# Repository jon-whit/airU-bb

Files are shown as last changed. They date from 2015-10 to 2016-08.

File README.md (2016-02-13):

airU
airU-bb
=====
The airU project is an interdisciplinary project by University of Utah Computer Science, Chemical Engineering, and Computer Engineering students who have designed a low cost air-quality sensor platform that is suited to improving our understanding of the Wasatch Front’s air quality challenges.  The project hopes to provide:

- A broad collection of air quality data, with tools that enable individuals to visualize, interpret, and download real-time data interactively.
- Low cost air quality stations that can communicate wireless with centralized databases (be it government or commercial)
- Innovative transportation routes based on air quality index rating (long term)

Contribute
----------
Please see the contribution guidelines in [CONTRIBUTING.md](./CONTRIBUTING.md).

- Issue Tracker: https://github.com/jon-whit/airU-bb/issues
- Source Code: https://github.com/jon-whit/airU-bb

Support
-------
If you are having issues, please feel free to email us.

We have a mailing list located at: airu-help@utah.edu

License
-------
See [LICENSE.md](./LICENSE.md)

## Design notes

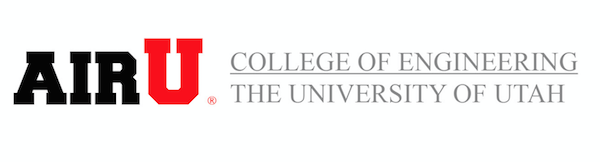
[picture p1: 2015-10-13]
airU.png

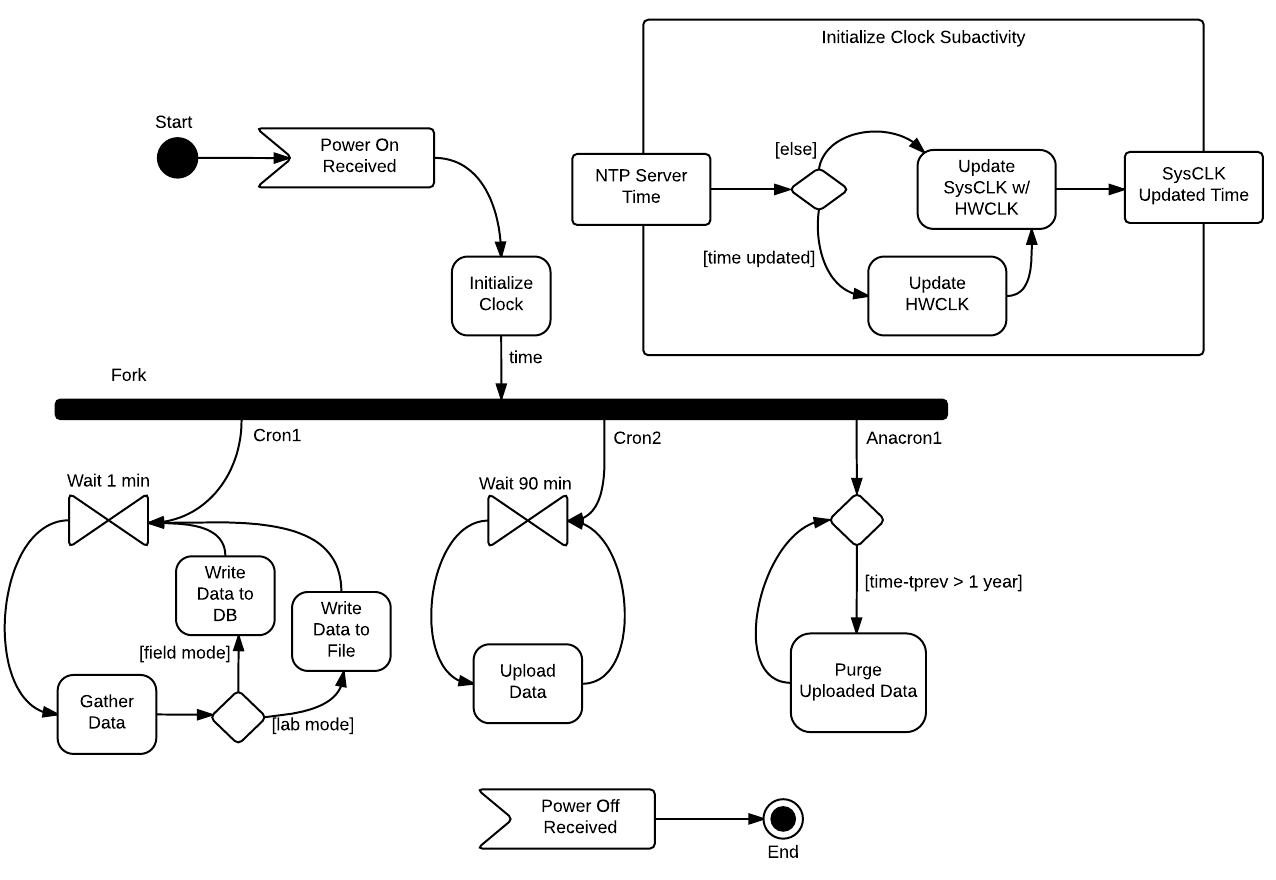
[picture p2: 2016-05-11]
Documents/Toolchain Activity Diagram.png

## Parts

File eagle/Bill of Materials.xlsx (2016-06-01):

Description | Quantity | Manufac. Part # | Mouser Part # | DigiKey Part # | MouseReel Available | DigiKeyReel Available | Unit Cost | Total Cost
Pressure Sensor & Digital Barometer | 1 | BMP180 | 262-BMP180 (http://www.mouser.com/ProductDetail/Bosch-Sensortec/BMP180/?qs=d72FGnIDsgTlLIC5YM2WKA%3D%3D) | N/A | Yes | N/A | $3.70 | $3.70
DHT22 Temp/Humidity Sensor | 1 | 385 (https://www.adafruit.com/products/385) | 485-385 (http://www.mouser.com/ProductDetail/Adafruit/385/) | N/A | Yes | N/A | $9.95 | $9.95
MICS 4514 (CO/NO2) Sensor | 1 | MICS-4514 (http://www.cdiweb.com/ProductDetail/MICS4514-SGX-Sensortech-Limited-formerly-e2v/333417/) | N/A | N/A | N/A | N/A | $9.72 | $9.72
MTK3339 GPS Chipset | 1 | Ultimate GPS Module (https://www.adafruit.com/products/790) |  |  |  |  | $29.95 | $29.95
DS1307 (Real Time Clock) | 1 | DS1307+ (http://www.mouser.com/ds/2/256/DS1307-99500.pdf) | 700-DS1307 (http://www.mouser.com/ProductDetail/Maxim-Integrated/DS1307+/?qs=sGAEpiMZZMsWkX3fPoxIPao0OKuDwxf4) | N/A | No | N/A | $3.32 | $3.32
U.FL RECEPTACLE SMT | 1 | 798-U.FL-R-SMT-110 (http://www.mouser.com/ProductDetail/Hirose-Connector/UFL-R-SMT-110/) | U.FL-R-SMT-1(10) (http://www.mouser.com/ProductDetail/Hirose-Connector/UFL-R-SMT-110/) | N/A | Yes | N/A | $1.29 | $1.29
SMD Green LED 571nm | 1 | 59-LTST-C230KGKT (http://www.mouser.com/ProductDetail/Lite-On/LTST-C230KGKT/?qs=sGAEpiMZZMseGfSY3csMkdPLvDBdRu8edtj8jOiqvGY%3d) | LTST-C230KGKT (http://www.mouser.com/ProductDetail/Lite-On/LTST-C230KGKT/?qs=sGAEpiMZZMseGfSY3csMkdPLvDBdRu8edtj8jOiqvGY%3d) | 160-1456-6-ND (http://www.digikey.com/product-detail/en/LTST-C230KGKT/160-1456-6-ND/1888661) | Yes | Yes | $0.64 | $0.64
PMS3003 Wire Housing | 1 | 53261-0871 (http://www.mouser.com/ds/2/276/0532610871_PCB_HEADERS-171054.pdf) | 538-53261-0871 (http://www.mouser.com/ProductDetail/Molex/53261-0871/?qs=%2b72YyncTwW%2bggfdCJ7Netw%3D%3D) | WM7626DKR-ND (http://www.digikey.com/product-detail/en/0532610871/WM7626DKR-ND/1846794) | Yes | Yes | $1.82 | $1.82
Ferrite Bead | 1 | MMZ2012R102A (http://www.mouser.com/ds/2/400/e9412_mmz-24297.pdf) | 810-MMZ2012R102A (http://www.mouser.com/ProductDetail/TDK/MMZ2012R102A/) | 445-1555-1-ND (http://www.digikey.com/product-detail/en/MMZ2012R102AT000/445-1555-1-ND/571885) | Yes | Yes | $0.11 | $0.11
SPDT Switch (SMT) | 1 | PCM12SMTR (http://www.mouser.com/ds/2/60/PCM_7jan16-24112.pdf) | 611-PCM12SMTR (http://www.mouser.com/ProductDetail/CK-Components/PCM12SMTR/?qs=sGAEpiMZZMtHXLepoqNyVcCjmOJVOBZeAfXRWWbW3TQ%3d) |  |  |  | $0.77 | $0.77
32.768kHz oscillator | 1 | FX122-327 (http://www.foxonline.com/pdfs/FX122.pdf) | N/A | 631-1261-1-ND (http://www.digikey.com/product-search/en?keywords=631-1261-1-ND) | N/A | Yes | $1.02 | $1.02
20mm Coin Cell Battery Holder | 1 | 12BH002-GR (http://www.mouser.com/ds/2/209/epd_10012015_12BH002-GR-770925.pdf) | 12BH002-GR (http://www.mouser.com/ProductDetail/Eagle-Plastic-Devices/12BH002-GR/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) |  |  |  | $0.46 | $0.46
SMD 1206 1/4watt 10Kohms 1% by Vishay | 5 | CRCW120610K0FKEA (http://www.mouser.com/ProductDetail/Vishay-Dale/CRCW120610K0FKEA/) | 71-CRCW1206-10K-E3 (http://www.mouser.com/ProductDetail/Vishay-Dale/CRCW120610K0FKEA/) | 541-10.0KFDKR-ND (http://www.digikey.com/product-detail/en/CRCW120610K0FKEA/541-10.0KFDKR-ND/1183732) | Yes | Yes | $0.37 | $1.86
SMD 1206 1/4watt 1Kohms 1% | 1 | RK73H2BTTD1001F (http://www.mouser.com/ProductDetail/KOA-Speer/RK73H2BTTD1001F/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) | 660-RK73H2BTTD1001F (http://www.mouser.com/ProductDetail/KOA-Speer/RK73H2BTTD1001F/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) |  |  |  | $0.10 | $0.10
SMD 1206 1/4watt 82ohms 1% by Vishay | 2 | CRCW120682R0FKEA (http://www.mouser.com/ds/2/427/dcrcwe3-109170.pdf) | 71-CRCW1206-82-E3 (http://www.mouser.com/ProductDetail/Vishay-Dale/CRCW120682R0FKEA/) | 541-82.0FCT-ND (http://www.digikey.com/product-detail/en/CRCW120682R0FKEA/541-82.0FCT-ND/1181636) | Yes | Yes | $0.10 | $0.20
SMD 1206 1/4watt 51ohms 1% by Vishay | 1 | CRCW120651R0FKEA (http://www.mouser.com/ds/2/427/dcrcwe3-109170.pdf) | 71-CRCW1206-51-E3 (http://www.mouser.com/ProductDetail/Vishay-Dale/CRCW120651R0FKEA/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) | 541-51.0UCT-ND (http://www.digikey.com/product-detail/en/CRCW120651R0FKEAHP/541-51.0UCT-ND/2826136) | Yes | Yes | $0.10 | $0.10
SMD 1206 1/4watt 620ohms 1% by Vishay | 1 | CRCW1206620RFKEA (http://www.mouser.com/ds/2/427/dcrcwe3-109170.pdf) | 71-CRCW1206-620-E3 (http://www.mouser.com/ProductDetail/Vishay-Dale/CRCW1206620RFKEA/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) | 541-620FTR-ND (http://www.digikey.com/product-detail/en/CRCW1206620RFKEA/541-620FTR-ND/1176621) | Yes | Yes | $0.10 | $0.10
SMD 1206 1/4watt 453ohms 1% by Vishay | 1 | CRCW1206453RFKEA (http://www.mouser.com/ds/2/427/dcrcwe3-109170.pdf) | 71-CRCW1206-453-E3 (http://www.mouser.com/ProductDetail/Vishay-Dale/CRCW1206453RFKEA/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) | N/A | Yes | N/A | $0.10 | $0.10
SMD 1206 1/4watt 62kohms 1% by Vishay | 1 | CRCW120662K0FKEA (http://www.mouser.com/ds/2/427/dcrcwe3-109170.pdf) | 71-CRCW1206-62K-E3 (http://www.mouser.com/ProductDetail/Vishay-Dale/CRCW120662K0FKEA/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) | 541-62.0KFCT-ND (http://www.digikey.com/product-detail/en/CRCW120662K0FKEA/541-62.0KFCT-ND/1181965) | Yes | Yes | $0.10 | $0.10
SMD 1206 1/4watt 33k0hms 1% by Vishay | 1 | CRCW120633K0FKEA (http://www.mouser.com/ds/2/427/dcrcwe3-109170.pdf) | 71-CRCW1206-33K-E3 (http://www.mouser.com/ProductDetail/Vishay-Dale/CRCW120633K0FKEA/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) | 541-33.0KFCT-ND (http://www.digikey.com/product-detail/en/CRCW120633K0FKEA/541-33.0KFCT-ND/1181931) | Yes | Yes | $0.10 | $0.10
SMD/SMT 1206 16volts 0.1uF X7R 10% | 4 | C1206C104K4RACTU (http://www.digikey.com/product-detail/en/C1206C104K4RACTU/399-9305-6-ND/3523376) | 80-C1206C104K4R (http://www.mouser.com/Search/ProductDetail.aspx) | 399-9305-6-ND (http://www.digikey.com/product-detail/en/C1206C104K4RACTU/399-9305-6-ND/3523376) | Yes | Yes | $0.36 | $1.43
SMD/SMT 1206 10uF 10volts X5R 10% | 2 | GRM31CR61A106KA01L (http://www.mouser.com/ProductDetail/Murata-Electronics/GRM31CR61A106KA01L/) | 81-GRM426R106K10L (http://www.mouser.com/ProductDetail/Murata-Electronics/GRM31CR61A106KA01L/) | GRM31CR61A106KA01L (http://www.digikey.com/product-detail/en/GRM31CR61A106KA01L/490-1820-6-ND/1825987) | Yes | Yes | $0.55 | $1.11
N-Channel MOSFET | 1 | BSS138LT1G (http://www.mouser.com/ds/2/308/BSS138LT1-D-104046.pdf) | 863-BSS138LT1G (http://www.mouser.com/ProductDetail/ON-Semiconductor/BSS138LT1G/) | BSS138LT1GOSCT-ND (http://www.digikey.com/product-detail/en/BSS138LT1G/BSS138LT1GOSCT-ND/917858) | Yes | Yes | $0.24 | $0.24
OSH Park PCBs | 3 | $38 | $13 per board
Total Estimated Cost per Board | $81.19

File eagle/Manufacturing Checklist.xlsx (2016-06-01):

 | Quantity | Value/Description | Unit | Additional | Key
Passives (No Orientation) | Resistors
 | 5 | 10k | Ohm |  | Oven Soldered
 | 1 | 1 | Ohm |  | Hand Soldered
 | 1 | 51 | Ohm
 | 2 | 82 | Ohm
 | 1 | 33k | Ohm
 | 1 | 453 | Ohm
 | 1 | 62 | Ohm
 | 1 | 620 | Ohm
 | Capacitors
 | 4 | 0.1u | Farad
 | 2 | 10u | Farad
 | 1 | LED | N/A
 | 1 | Ferrite Bead | N/A
 | 1 | 32.768k Oscillator | Hz
 | Sensors
 | 1 | BMP180 | Pressure, Temp, Alt
 | 1 | MTK3339 (GPS) | N/A | Large and square
 | 1 | MICS4514 | CO & NO2
 | 1 | DHT22 | Temp, Humidity
 | Special
 | 1 | N-channel MOSFET | N/A | 3-peg chip
 | 1 | Slide Switch | N/A
 | 1 | U.FL Receptical | N/A | Beneath GPS chip
 | 1 | Coin Cell Battery Clip | N/A | Back side of board
 | 1 | Wire Housing for PMS3003 | N/A | Back side of board
 | 1 | DS1307 (RTC) | N/A | Top side through-hole

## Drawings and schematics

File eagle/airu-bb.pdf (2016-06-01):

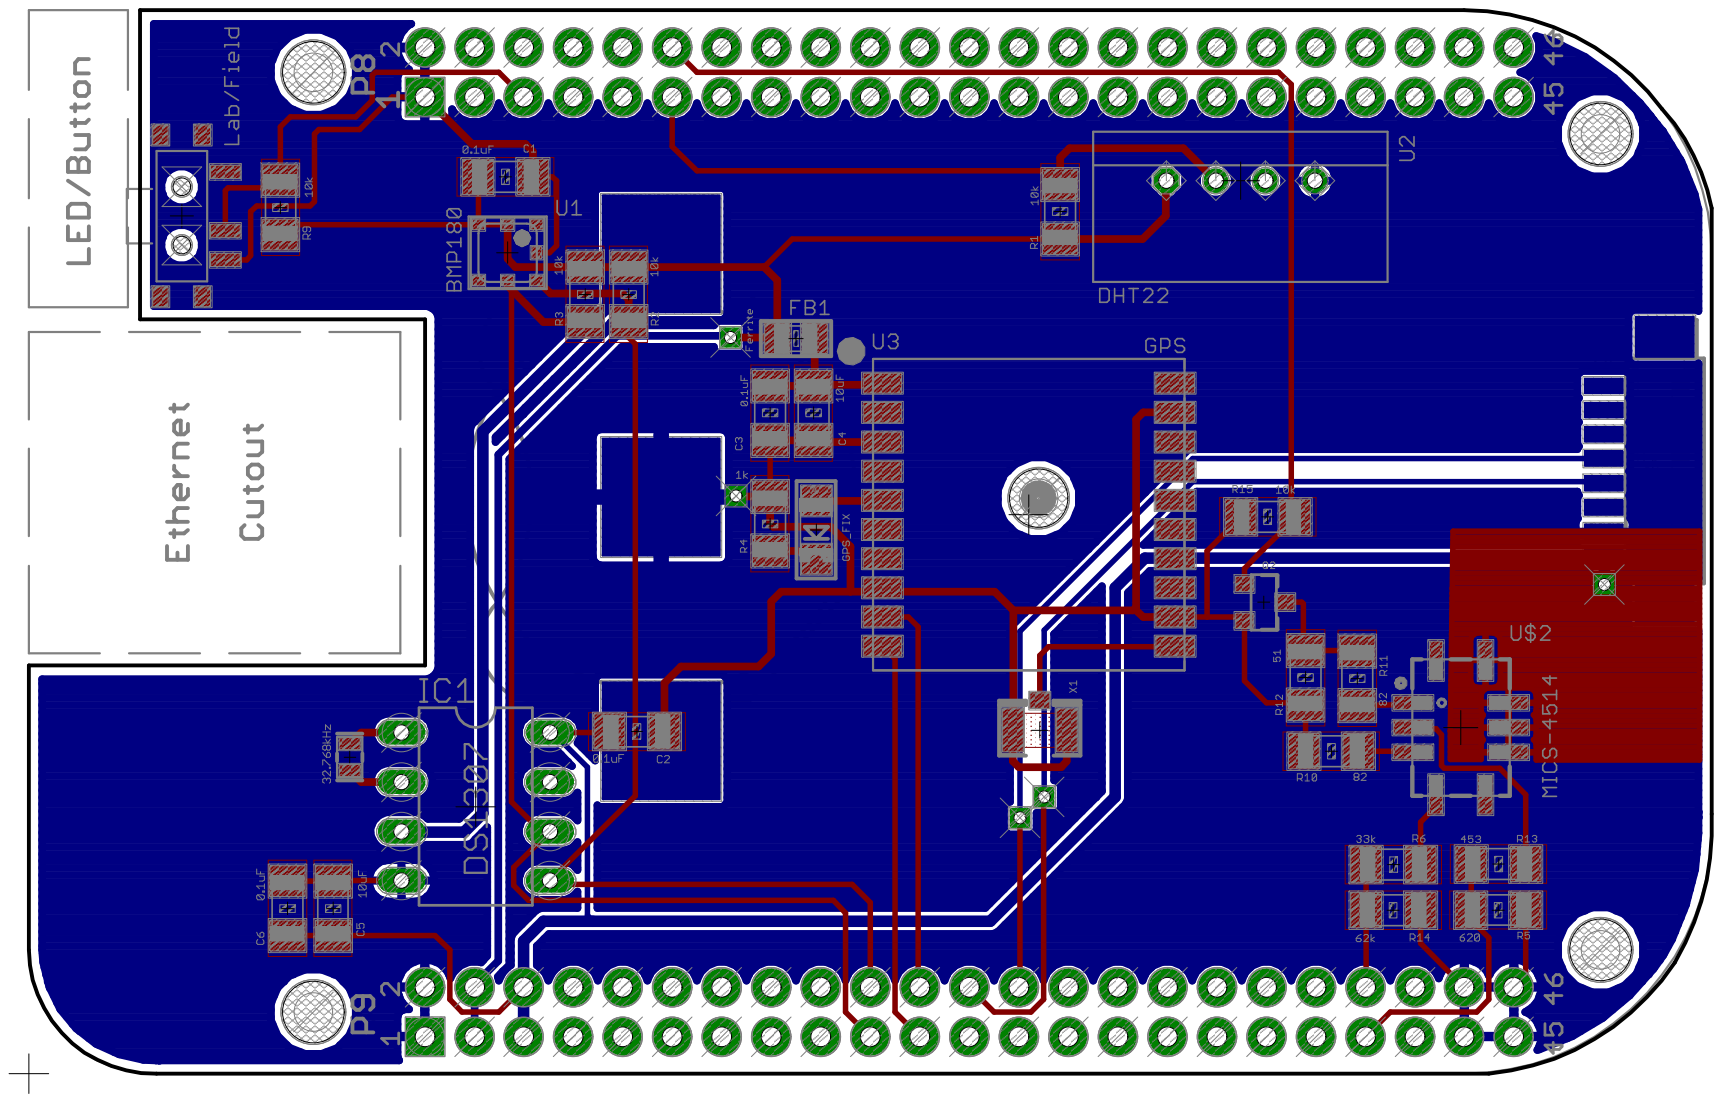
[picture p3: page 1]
BAT1

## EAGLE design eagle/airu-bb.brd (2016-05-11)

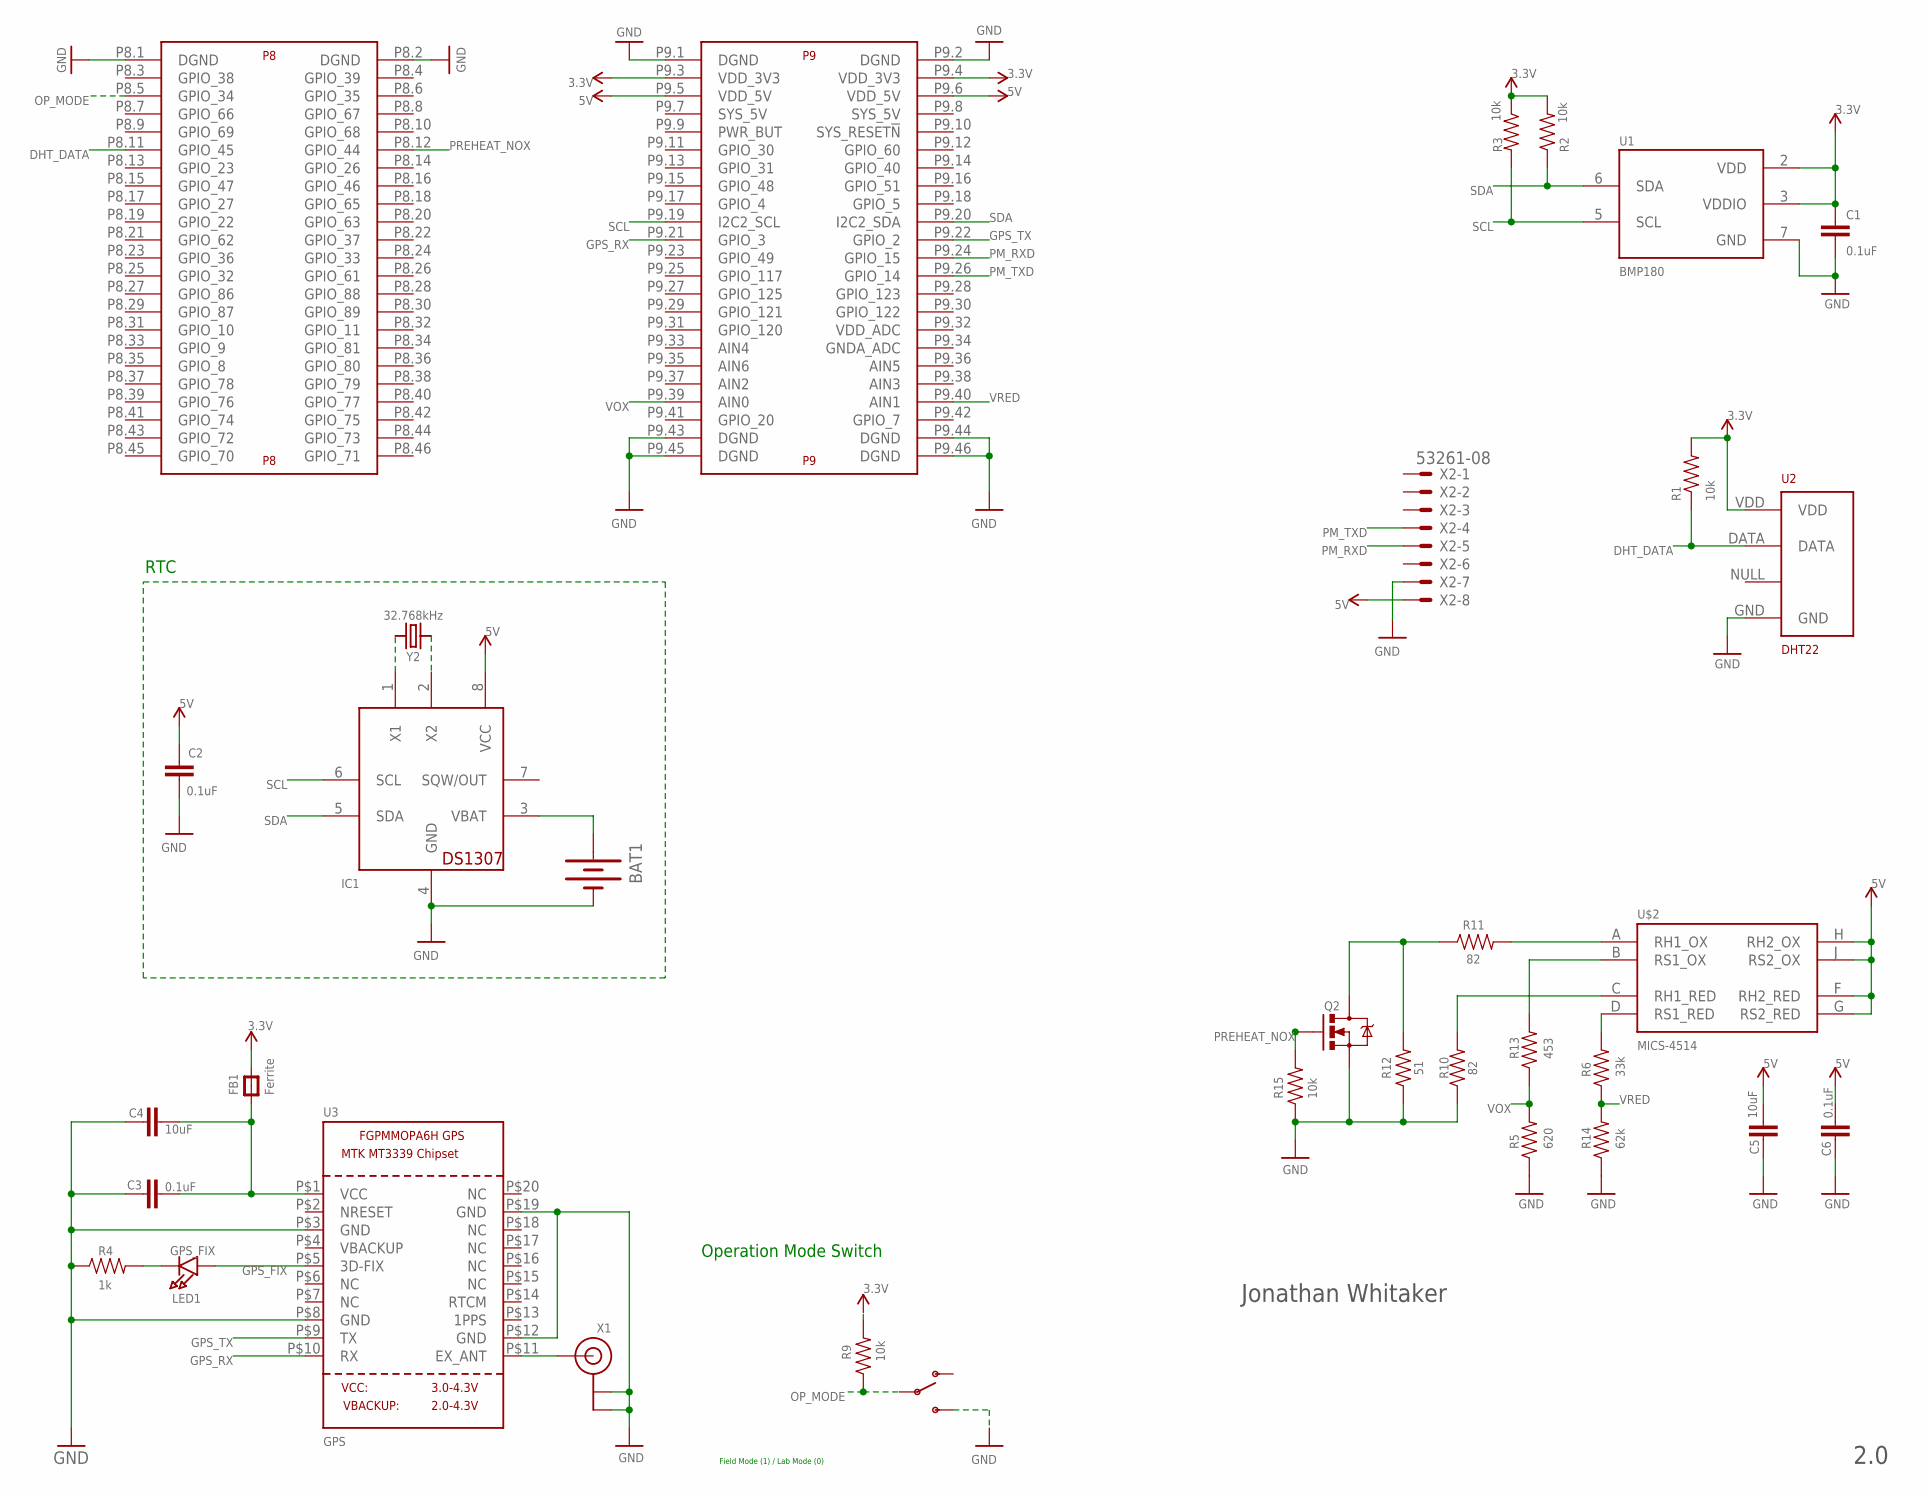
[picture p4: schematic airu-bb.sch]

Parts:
BAT1: BATTERY20SMD; BATTCON_20MM
C1, C2, C3, C6: 0.1uF; 1206
C4, C5: 10uF; 1206
FB1: Ferrite; 0805
IC1: DS1307; DIL08
LED1: GPS_FIX; CHIPLED_1206
Q2: MOSFET-NCHANNELAO3404A; SOT23-3
R1, R2, R3, R9, R15: 10k; 1206
R4: 1k; 1206
R5: 620; 1206
R6: 33k; 1206
R10, R11: 82; 1206
R12: 51; 1206
R13: 453; 1206
R14: 62k; 1206
U1: BMP180
U2: DHT22; RHT03_DHT-22
U3: GPS; FGPMMOPA6H
U$1: BEAGLE_BONE_BLACK_CAPE
U$2: MICS-4514; MICS_10-SMD
U$3: SWITCH_SPDT; KPS-1290
X1: ANTENNA_U.FL; U.FL
X2: 53261-08
Y2: 32.768kHz; 2-SMD

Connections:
3.3V: C1.1, FB1.2, R1.2, R2.2, R3.1, R9.2, U1.2 (VDD), U1.3 (VDDIO), U2.VDD, U$1.P9.3 (VDD_3V3), U$1.P9.4 (VDD_3V3)
5V: C2.2, C5.2, C6.2, IC1.8 (VCC), U$1.P9.5 (VDD_5V), U$1.P9.6 (VDD_5V), U$2.F (RH2_RED), U$2.G (RS2_RED), U$2.H (RH2_OX), U$2.J (RS2_OX), X2.8
DHT_DATA: R1.1, U2.DATA, U$1.P8.11 (GPIO_45)
GND: BAT1.2 (-), C1.2, C2.1, C3.1, C4.1, C5.1, C6.1, IC1.4 (GND), Q2.2 (S), R4.1, R5.1, R10.1, R12.1, R14.1, R15.1, U1.7 (GND), U2.GND, U3.P$3 (GND), U3.P$8 (GND), U3.P$12 (GND), U3.P$19 (GND), U$1.P8.1 (DGND), U$1.P8.2 (DGND), U$1.P9.1 (DGND), U$1.P9.2 (DGND), U$1.P9.43 (DGND), U$1.P9.44 (DGND), U$1.P9.45 (DGND), U$1.P9.46 (DGND), U$3.S, X1.1 (GND), X1.2 (GND), X2.7
GPS_FIX: LED1.A, U3.P$5 (3D-FIX)
GPS_RX: U3.P$10 (RX), U$1.P9.21 (GPIO_3)
GPS_TX: U3.P$9 (TX), U$1.P9.22 (GPIO_2)
unnamed: C3.2, C4.2, FB1.1, U3.P$1 (VCC)
unnamed: U3.P$11 (EX_ANT), X1.3 (SIGNAL)
unnamed: LED1.C, R4.2
unnamed: R10.2, U$2.C (RH1_RED)
unnamed: R13.2, U$2.B (RS1_OX)
unnamed: Q2.3 (D), R11.1, R12.2
unnamed: R6.2, U$2.D (RS1_RED)
unnamed: R11.2, U$2.A (RH1_OX)
unnamed: BAT1.1 (+), IC1.3 (VBAT)
unnamed: IC1.1 (X1), Y2.1
unnamed: IC1.2 (X2), Y2.2
OP_MODE: R9.1, U$1.P8.5 (GPIO_34), U$3.P
PM_RXD: U$1.P9.24 (GPIO_15), X2.5
PM_TXD: U$1.P9.26 (GPIO_14), X2.4
PREHEAT_NOX: Q2.1 (G), R15.2, U$1.P8.12 (GPIO_44)
SCL: IC1.6 (SCL), R3.2, U1.5 (SCL), U$1.P9.19 (I2C2_SCL)
SDA: IC1.5 (SDA), R2.1, U1.6 (SDA), U$1.P9.20 (I2C2_SDA)
VOX: R5.2, R13.1, U$1.P9.39 (AIN0)
VRED: R6.1, R14.2, U$1.P9.40 (AIN1)

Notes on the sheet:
Jonathan Whitaker
2.0
RTC
Operation Mode Switch
Field Mode (1) / Lab Mode (0)

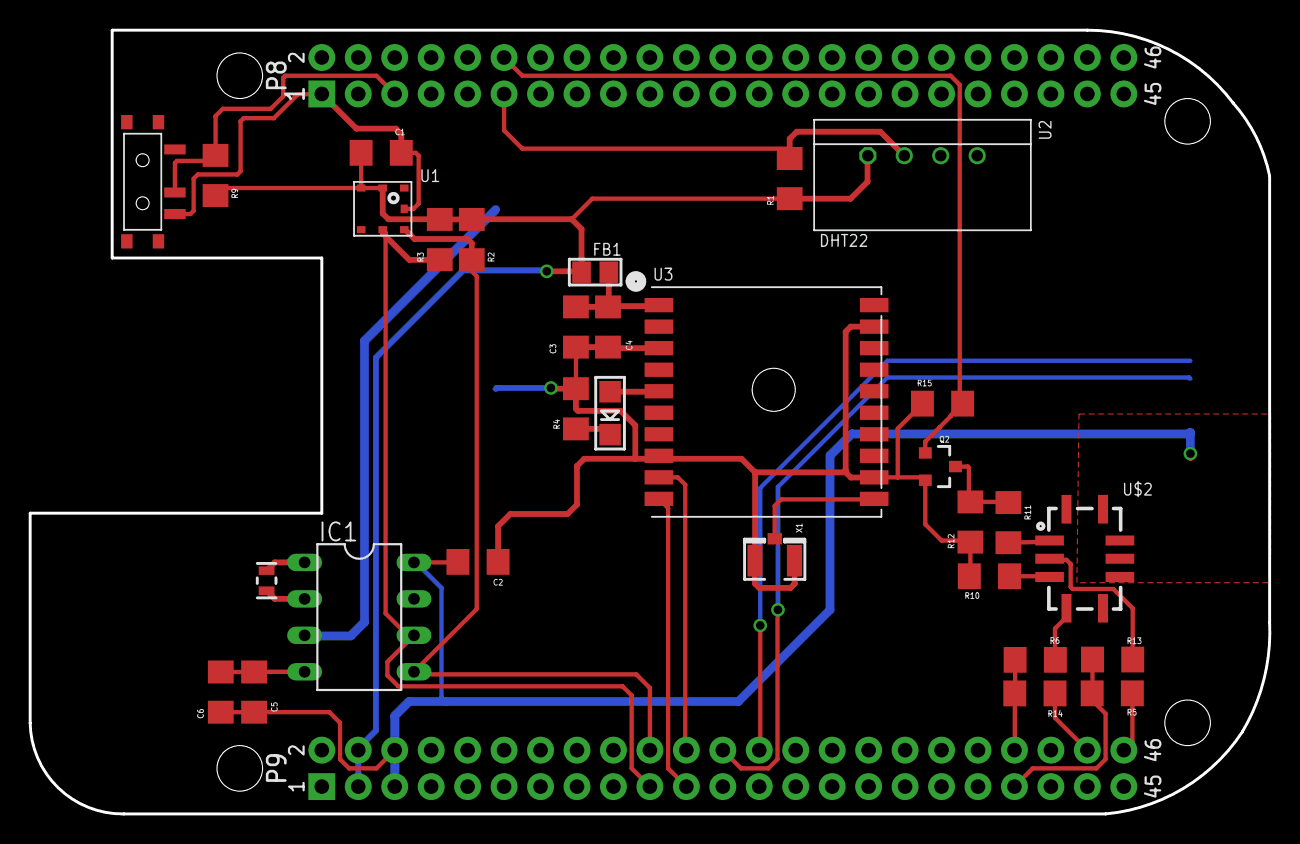
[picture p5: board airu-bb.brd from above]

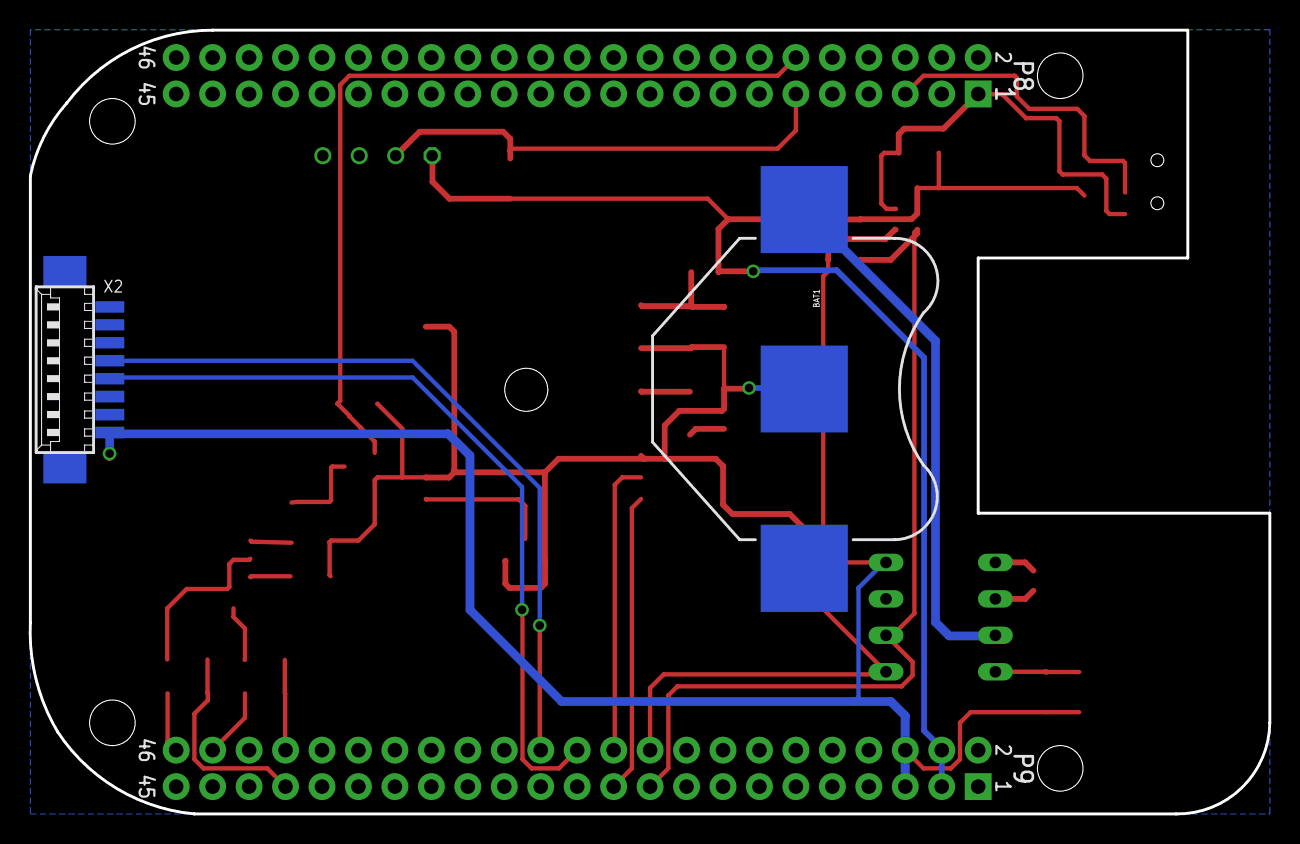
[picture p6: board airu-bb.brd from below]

Board: 2 copper layers, 86.4 x 54.6 mm, 33 parts (2 on the bottom side), 26 nets.

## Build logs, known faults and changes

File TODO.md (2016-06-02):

* Rebuild base images with station registration support
  * Element14 image
  * BeagleBone.org image
* Add CO2/NO2 support in the main library
* Add improved components:
  * Silicon Labs Si7006 (I2C temperature & humidity) - $1.66 compared to $10
* Look into WiFi support with ESP8266

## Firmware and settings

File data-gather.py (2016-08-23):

"""
data-gather.py

Author: Jonathan Whitaker
Email: jon.b.whitaker@gmail.com
Date: April 21, 2016

data-gather.py is an integral part of the AirU toolchain, serving as the script
which collects the data from the various sensors onboard an AirU station. This 
script is designed to run using a Cron. It was designed to write the data to an
internal database if the station is set to run in Field Mode, or it will write 
the data to a CSV file named by the current time and date if the station is in 
Lab Mode.
"""
import logging
import datetime
import sys
import time
import serial
import Adafruit_BMP.BMP085 as BMP085
import Adafruit_BBIO.GPIO as GPIO
from lib.airu import utils
from lib.airu import airstation
from lib.airu.airstation import AirStation
from lib.airu.dbmodels import *

# Setup the Logging interface for this script
rootLogger = logging.getLogger()
rootLogger.setLevel(logging.INFO)

if __name__ == '__main__':
    
    # Setup logging
    logFormatter = logging.Formatter('%(asctime)s %(name)-12s %(levelname)-8s %(message)s')
    logfilename = "/var/log/{0}.log".format(time.strftime("%m-%d-%Y"))
    fileHandler = logging.FileHandler(logfilename)
    fileHandler.setFormatter(logFormatter)
    rootLogger.addHandler(fileHandler)
    
    # Setup the GPIO input pin for the mode switch
    GPIO.setup(airstation.MODE_SWITCH, GPIO.IN)
    
    # If the mode switch is "high", the station is in field mode
    if GPIO.input(airstation.MODE_SWITCH):
        mode = airstation.FIELD_MODE
    else:
        mode = airstation.LAB_MODE

    # Sample the sensors
    rootLogger.info('Capturing Measurements from the Onboard Sensors...')
    pm_ser = serial.Serial(port=airstation.PM_PORT, baudrate=9600, rtscts=True, dsrdtr=True)
    with AirStation(BMP085.BMP085(), utils.GpsPoller(), pm_ser, mode) as station:
        temp = station.get_temp()
        rootLogger.info('Temperature:      {0:0.1f} C'.format(temp))
        humidity = station.get_humidity()
        rootLogger.info('Humidity:         {0:0.1f} %'.format(humidity))
        pressure = station.get_pressure()
        rootLogger.info('Pressure:         {0:0.1f} Pa'.format(pressure))
        altitude = station.get_altitude()
        rootLogger.info('Altitude:         {0:0.1f} m'.format(altitude))
        
        if mode == airstation.FIELD_MODE:
            lon, lat = station.get_location()
            rootLogger.info('Latitude:         {0:0.1f} deg'.format(lat))
            rootLogger.info('Longitude:        {0:0.1f} deg'.format(lon))

        (pm1, pm25, pm10) = station.get_pm()
        rootLogger.info('PM1.0:            {0:0.1f} ug/m3'.format(pm1))
        rootLogger.info('PM2.5:            {0:0.1f} ug/m3'.format(pm25))
        rootLogger.info('PM10:             {0:0.1f} ug/m3'.format(pm10))

        co  = station.get_co()
        rootLogger.info('CO:               {0:0.1f} volts'.format(co))
        no2 = station.get_no2()
        rootLogger.info('NO2:              {0:0.1f} volts'.format(no2))
    rootLogger.info('Done Capturing Measurements.')
    
    """
    Check the operation mode. If the station is in field mode, write the measurements 
    to the internal database. Otherwise, write the measurements to a CSV file named by 
    the current date and time.
    """ 
    if mode == airstation.FIELD_MODE:
        rootLogger.info('Station Set to Field Mode.')
        rootLogger.info('Setting Up Internal Database...')
        db.init('/root/air-metrics.db')
        db.connect()
        db.create_tables([AirMeasurement], True)
        rootLogger.info('Database Setup Complete.')
        
        # Save the captured measurements to the database
        rootLogger.info('Saving Captured Measurements to the Database...')
        measurement = AirMeasurement(type='Temperature', value=temp, unit='C', latitude=lat, longitude=lon)
        measurement.save()
        measurement = AirMeasurement(type='Humidity', value=humidity, unit='%', latitude=lat, longitude=lon)
        measurement.save()
        measurement = AirMeasurement(type='Pressure', value=pressure, unit='Pascal', latitude=lat, longitude=lon)
        measurement.save()
        measurement = AirMeasurement(type='Altitude', value=altitude, unit='M', latitude=lat, longitude=lon)
        measurement.save()
        measurement = AirMeasurement(type='PM1.0', value=pm1, unit='UG/M3', latitude=lat, longitude=lon)
        measurement.save()
        measurement = AirMeasurement(type='PM2.5', value=pm25, unit='UG/M3', latitude=lat, longitude=lon)
        measurement.save()
        measurement = AirMeasurement(type='PM10.0', value=pm10, unit='UG/M3', latitude=lat, longitude=lon)
        measurement.save()
        rootLogger.info('Measurements Saved.\n')
    else:
        rootLogger.info('Station Set to Lab Mode.')
        # Otherwise append the measurement to a file with the current date and time
        outputfile = "/media/sdcard/{0}.csv".format(time.strftime("%m-%d-%Y"))
        rootLogger.info("Opening CSV File '{0}' for Writing...".format(outputfile))
        fh = open(outputfile, 'a')
        
        rootLogger.info("Writing Sample to File...")
        timenow = datetime.datetime.utcnow()
        datastr = "{0},{1},{2},{3},{4},{5},{6},{7}\n".format(timenow, temp, humidity, pressure, altitude, pm1, pm25, pm10)
        fh.write(datastr)
        rootLogger.info("Sample Successfully Written.\n")
        

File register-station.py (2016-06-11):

"""
register-station.py

Author: Jonathan Whitaker
Email: jon.b.whitaker@gmail.com
Date: April 21, 2016

register-station.py is a script which serves to send a registration call to the
AirU registration endpoint. This script is designed to run at station bootup. If
the station is already registered, the post conditions of this script will have
no effect.
"""
import requests
import json
from lib.airu.utils import get_mac

if __name__ == '__main__':
  """
  Uploads the MAC address to the server for station registration.
  """

  url     = 'http://dev.air.eng.utah.edu/api/stations/ping'
  headers = {'Content-Type': 'application/json'}
  message = {"id": get_mac('eth0').replace(':', '')}

  print message

  r = requests.post(url, data=json.dumps(message), headers=headers)
  if r.status_code == 200:
    print 'Device Registered.'
  else:
    print 'A server error occurred.'

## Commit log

2015-10-10 Created a main app and AirStation class w/ utils
    This commit includes an initial implementation of an AirStation class with
    supporting utilities, as well as an initial template for the main application
    entry point.
    # Please enter the commit message for your changes. Lines starting
    # with '#' will be ignored, and an empty message aborts the commit.
    # On branch master
    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
2015-10-10 Added initial Eagle schematic w/ support libs.
    This commit includes the initial Eagle schematic file and the supporting
    libraries used in the schematic. It also includes a change to the .gitignore
    file so that Eagle swap files are not added to the working tree.
    [airu-schematic.sch]
2015-10-11 Added MCP3008 ADC to the schematic, and BOM.
    This commit adds an MCP3008 ADC to the schematic, which is used for
    converting the analog sensor values to a digital sequence. This commit
    also includes a preliminary Bill of Materials that will be used to order
    components in bulk for assembly (post fabrication).
    [Bill of Materials.xlsx, airu-schematic.sch]
2015-10-11 Added method stubs for the additional analog sensors.
    This commit includes intial method stubs for the various analog sensors
    that will be on each air station.
2015-10-15 Added a retry decorator and an ADC read function.
    This commit includes a minor improvement which consists of a retry decorator
    that will attempt to get a sensor reading a given number of times, and throw
    an exception if a reading is not read out within the retry period. This commit
    also includes an added utility function to read the values from the MCP3008 ADC
    chip through the SPI hardware interface on the Raspberry Pi.
2015-10-30 Added the MQ-7 circuit and supporting code.
    This commit adds the MQ-7 circuit to the airU board schematic. It
    also includes the supporting code needed to read from the sensor.
    [airu-schematic.sch]
2015-12-22 Added schematic copy for BeagleBone
    [airu-schematic-bb.sch, airu-schematic-pi.sch]
2015-12-29 Added schematic for BeagleBone Black
    [airu-schematic-bb.sch]
2016-01-03 Added PMS3003 supporting code.
    This commit includes all of the code needed to interface with the
    PMS3003 particulate matter sensor.
2016-01-07 Updated BOM and added slight improvements to the PCB layout.
    [Bill of Materials.xlsx, airu-schematic-bb.sch]
2016-01-28 Finalized AirU schematic and board V1.0!
    This commit includes the last changes for V1.0 of the AirU air quality board.
    These changes include:
    1. Bill of Materials
    2. Final schematic
    3. Final board layout
    4. PDFs of the schematic and board layout.
    [Bill of Materials-v1.xlsx, Bill of Materials.xlsx, airu-schematic-bb-v1.brd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]
2016-02-13 Made improvements to layout and added silkscreen components.
    This commit includes improvments to the physical layout as well as
    comments on the silkscreen layer.
    [Bill of Materials-v1.xlsx, airu-schematic-bb-v1.brd, airu-schematic-bb-v1.sch]
2016-02-13 Fixed schematic and layout PDFs.
2016-03-23 Refactored toolchain.
    This commit refactored the old airU.py script so that it acts as a toolchain of 3 support scripts. The data-dumpy.py script is used to collect data from the sensors and write the results to a local d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
2016-03-30 Adds device registration script and MACAddress retrieval.
    - url needs to be updated when server endpoint is implemented
    - to test: ensure MACAddress retrieval is accurate and
    does not change on BB
2016-03-30 Modifies units to conform to server API's case sensitivity for parameter units.
2016-03-30 Adds mock data script to populate non-root level DB. Adds functionality to data-upload.
    - To Test:
    - make sure MACAddress is registered with server
    OR hardcode { "Id": "T1000" } as Station value in upload JSON
    - run mock_data.py
    - remove '/root/' from db.init in data-upload.py
    - run data-upload
    - when API is fixed, this should print 200
    [data-upload.py]
2016-04-06 Added SPDT switch for operation mode and added RTC
    This commit adds improvements to the schematic which includes a SPDT switch
    that will be used to configure the operation mode of the station (lab/field use),
    as well as a real-time clock so that time stamps can be used accurately offline.
    [airu-bb-v2.brd, airu-bb-v2.sch]
2016-04-09 fixes error in post json
    [register-station.py]
2016-04-09 adds workaround for server api bug
    [data-upload.py]
2016-04-11 Added mode descriptions to the schematic
    [airu-bb-v2.sch]
2016-04-11 Cleaned up eagle/lib directory.
    [airu-bb-v2.brd]
2016-04-21 Added modifications for AirU V2.0
    This commit includes all modifications needed for AirU V2.0. This includes:
    * Schematic additions integrating a mode button and real-time clock
    * Board layout revisions to integrate the added components
    * Changes to the BOM to reflect the new design
    I also reorganized the repository structure.
    [Bill of Materials-v1.xlsx, Bill of Materials.xlsx, airu-bb.brd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]
2016-04-21 Added Operation Mode support.
    This commit includes the necessary modifications to support the
    Operation Mode button which was added in the V2.0 AirU stations.
2016-05-11 Fixed a typo in the GPIO function call
    [data-gather.py]
2016-05-11 Finalized RTC hardware and software additions
    This commit adds final changes to the AirU software for
    version 2.0 boards.
2016-05-11 Fixed poorly merged units
    [data-gather.py]
2016-06-01 Added board layout PDF and manufacturing checklist
    [Bill of Materials.xlsx, Manufacturing Checklist.xlsx]
2016-06-11 Added the JSON package import
    The JSON package was missing in the import list.
    [register-station.py]
2016-07-19 Added pin constant for the PM sensor.
2016-07-19 Fixed port name typo for PM sensor.
2016-08-04 Added CO/NO2 gas sensor support
    This commits adds the ADC functionality needed to sample
    the CO/NO2 sensors.
2016-08-04 Update airstation.py
    Fixed pin assignment for CO and NO2 sensors.
2016-08-23 Added UTC timestamp to sample output.
2016-08-23 Fixed merge conflict.
    This commit fixes a mistake that was made in the merging of my local copy and the remote copy that previously existed.
    [data-gather.py]

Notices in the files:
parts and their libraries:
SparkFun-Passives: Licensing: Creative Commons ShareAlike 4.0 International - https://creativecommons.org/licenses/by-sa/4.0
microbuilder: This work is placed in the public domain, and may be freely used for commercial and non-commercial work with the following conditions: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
